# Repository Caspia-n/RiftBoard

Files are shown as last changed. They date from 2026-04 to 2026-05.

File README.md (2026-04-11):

<h1>My Project</h1>
RiftBoard is a comprehensive devboard built around the RP2040 chipset, it features a very fancy (and time consuming) ground fill, some 3v3 and some VBUS, also lots of GND. I built it mainly for testing and using sensors and actuators, either on their own or working together.
<h1>Why?</h1>
I started this project because I wanted to get into hardware design and embedded electronics. But also because I love HackClub and what they do and really wanted to be a part of this, I thank you so much for the opportunities, and I also really want a hot plate for future projects :).

<h1>Pics</h1>


RiftBoard
RiftBoardBack

<h1>BOM</h1>
<table>
    <tr>
        <td>Mrf#</td>
        <td>Mfr.</td>
        <td>Order Qty.</td>
        <td>Unit Price(USD)</td>
        <td>Ext.Price(USD)</td>
        <td>LCSC#</td>
        <td>Package</td>
        <td>Min</td>
        <td>Mult</td>
        <td>SPQ</td>
        <td>Availability</td>
        <td>Stock Status</td>
        <td>Customer Notes</td>
        <td>Description</td>
        <td>Purpose</td>
        <td>Product Link</td>
    </tr>
    <tr>
        <td>CC0402KRX7R7BB104</td>
        <td>YAGEO</td>
        <td>100</td>
        <td>0.0010</td>
        <td>0.10</td>
        <td>C60474</td>
        <td>0402</td>
        <td>100</td>
        <td>100</td>
        <td>10000</td>
        <td>11898300</td>
        <td>In Stock</td>
        <td></td>
        <td>100nF ±10% 16V Ceramic Capacitor X7R 0402</td>
        <td>Capacitors for decoupling and stabilisation of powerlines</td>
        <td>https://www.lcsc.com/product-detail/C60474.html</td>
    </tr>
    <tr>
        <td>CL05A105KP5NNNC</td>
        <td>Samsung Electro-Mechanics</td>
        <td>100</td>
        <td>0.0023</td>
        <td>0.23</td>
        <td>C14445</td>
        <td>0402</td>
        <td>100</td>
        <td>100</td>
        <td>10000</td>
        <td>1500800</td>
        <td>In Stock</td>
        <td></td>
        <td>1uF ±10% 10V Ceramic Capacitor X5R 0402</td>
        <td>One for each power line</td>
        <td>https://www.lcsc.com/product-detail/C14445.html</td>
    </tr>
    <tr>
        <td>CL10A106KP8NNNC</td>
        <td>Samsung Electro-Mechanics</td>
        <td>50</td>
        <td>0.0080</td>
        <td>0.40</td>
        <td>C19702</td>
        <td>0603</td>
        <td>50</td>
        <td>50</td>
        <td>4000</td>
        <td>3665250</td>
        <td>In Stock</td>
        <td></td>
        <td>10uF ±10% 10V Ceramic Capacitor X5R 0603</td>
        <td>Caps for the stepdown converter</td>
        <td>https://www.lcsc.com/product-detail/C19702.html</td>
    </tr>
    <tr>
        <td>CL05C330JB5NNNC</td>
        <td>Samsung Electro-Mechanics</td>
        <td>100</td>
        <td>0.0036</td>
        <td>0.36</td>
        <td>C70465</td>
        <td>0402</td>
        <td>100</td>
        <td>100</td>
        <td>10000</td>
        <td>209500</td>
        <td>In Stock</td>
        <td></td>
        <td>33pF ±5% 50V Ceramic Capacitor C0G 0402</td>
        <td>Caps for the crystal</td>
        <td>https://www.lcsc.com/product-detail/C70465.html</td>
    </tr>
    <tr>
        <td>YLED0603B</td>
        <td>YONGYUTAI</td>
        <td>100</td>
        <td>0.0060</td>
        <td>0.60</td>
        <td>C19171394</td>
        <td>0603</td>
        <td>100</td>
        <td>100</td>
        <td>4000</td>
        <td>55000</td>
        <td>In Stock</td>
        <td></td>
        <td>Blue LED Indication - Discrete 2.6V~3.2V 0603</td>
        <td>Blue programmable LED</td>
        <td>https://www.lcsc.com/product-detail/C19171394.html</td>
    </tr>
    <tr>
        <td>YLED0603R</td>
        <td>YONGYUTAI</td>
        <td>100</td>
        <td>0.0061</td>
        <td>0.61</td>
        <td>C19171390</td>
        <td>0603</td>
        <td>100</td>
        <td>100</td>
        <td>4000</td>
        <td>267100</td>
        <td>In Stock</td>
        <td></td>
        <td>Red LED Indication - Discrete 1.8V~2.4V 0603</td>
        <td>Red programmable LED</td>
        <td>https://www.lcsc.com/product-detail/C19171390.html</td>
    </tr>
    <tr>
        <td>HX TYPE-C 16PIN</td>
        <td>hanxia</td>
        <td>5</td>
        <td>0.0704</td>
        <td>0.35</td>
        <td>C5178539</td>
        <td>SMD</td>
        <td>5</td>
        <td>5</td>
        <td>1000</td>
        <td>34690</td>
        <td>In Stock</td>
        <td></td>
        <td>USB-C (USB TYPE-C) Receptacle Connector 16 Position Surface Mount, Right Angle</td>
        <td>Usb interface</td>
        <td>https://www.lcsc.com/product-detail/C5178539.html</td>
    </tr>
    <tr>
        <td>PH2.54-1X20P-H25</td>
        <td>JXTCONN</td>
        <td>10</td>
        <td>0.0920</td>
        <td>0.92</td>
        <td>C42431804</td>
        <td>Through Hole,P=2.54mm</td>
        <td>5</td>
        <td>5</td>
        <td>200</td>
        <td>9870</td>
        <td>In Stock</td>
        <td></td>
        <td>Pin Header 20 Position 2.54mm Pitch Single Row Through Hole -40℃~+105℃</td>
        <td>Main Pin headers</td>
        <td>https://www.lcsc.com/product-detail/C42431804.html</td>
    </tr>
    <tr>
        <td>HX PH254-01-03-Z-L11.5 pcb pin header</td>
        <td>hanxia</td>
        <td>20</td>
        <td>0.0192</td>
        <td>0.38</td>
        <td>C52016391</td>
        <td>Through Hole,P=2.54mm</td>
        <td>20</td>
        <td>20</td>
        <td>2000</td>
        <td>9760</td>
        <td>In Stock</td>
        <td></td>
        <td>Pin Header 1 2.5mm 6mm 3P -40℃~+105℃ 3mm 2.54mm 3A 1kV 1x3P Through Hole,P=2.54mm Headers, Male Pins RoHS</td>
        <td>3pin-connector</td>
        <td>https://www.lcsc.com/product-detail/C52016391.html</td>
    </tr>
    <tr>
        <td>RC0402FR-075K1L</td>
        <td>YAGEO</td>
        <td>100</td>
        <td>0.0009</td>
        <td>0.09</td>
        <td>C105872</td>
        <td>0402</td>
        <td>100</td>
        <td>100</td>
        <td>10000</td>
        <td>1024700</td>
        <td>In Stock</td>
        <td></td>
        <td>5.1kΩ 62.5mW 50V Thick Film Resistor ±100ppm/℃ ±1% 0402 Chip Resistor - Surface Mount RoHS</td>
        <td>Pull-down resistors for CC1/2 on usb interface</td>
        <td>https://www.lcsc.com/product-detail/C105872.html</td>
    </tr>
    <tr>
        <td>FRC0402F27R0TS</td>
        <td>FOJAN</td>
        <td>100</td>
        <td>0.0006</td>
        <td>0.06</td>
        <td>C2909343</td>
        <td>0402</td>
        <td>100</td>
        <td>100</td>
        <td>10000</td>
        <td>443300</td>
        <td>In Stock</td>
        <td></td>
        <td>27Ω ±1% 62.5mW 0402 Thick Film Resistor</td>
        <td>Resistors for the differential pair to usb interface</td>
        <td>https://www.lcsc.com/product-detail/C2909343.html</td>
    </tr>
    <tr>
        <td>RC0402FR-071KL</td>
        <td>YAGEO</td>
        <td>100</td>
        <td>0.0008</td>
        <td>0.08</td>
        <td>C106235</td>
        <td>0402</td>
        <td>100</td>
        <td>100</td>
        <td>10000</td>
        <td>5051800</td>
        <td>In Stock</td>
        <td></td>
        <td>1kΩ 62.5mW 50V Thick Film Resistor ±100ppm/℃ ±1% 0402 Chip Resistor - Surface Mount RoHS</td>
        <td>One for the crystal and one for flash mem</td>
        <td>https://www.lcsc.com/product-detail/C106235.html</td>
    </tr>
    <tr>
        <td>RC0402FR-0710KL</td>
        <td>YAGEO</td>
        <td>100</td>
        <td>0.0008</td>
        <td>0.08</td>
        <td>C60490</td>
        <td>0402</td>
        <td>100</td>
        <td>100</td>
        <td>10000</td>
        <td>1433400</td>
        <td>In Stock</td>
        <td></td>
        <td>62.5mW 10kΩ 50V Thick Film Resistor ±100ppm/℃ ±1% 0402 Chip Resistor - Surface Mount RoHS</td>
        <td>Flash mem to power resistor</td>
        <td>https://www.lcsc.com/product-detail/C60490.html</td>
    </tr>
    <tr>
        <td>FRC0402F50R0TS</td>
        <td>FOJAN</td>
        <td>100</td>
        <td>0.0006</td>
        <td>0.06</td>
        <td>C51048227</td>
        <td>0402</td>
        <td>100</td>
        <td>100</td>
        <td>10000</td>
        <td>495800</td>
        <td>In Stock</td>
        <td></td>
        <td>62.5mW 50Ω 50V Thick Film Resistor ±100ppm/℃ ±1% 0402 Chip Resistor - Surface Mount RoHS</td>
        <td>50R resistor for Red LED</td>
        <td>https://www.lcsc.com/product-detail/C51048227.html</td>
    </tr>
    <tr>
        <td>0603WAF100JT5E</td>
        <td>UNI-ROYAL</td>
        <td>20</td>
        <td>0.0017</td>
        <td>0.03</td>
        <td>C22859</td>
        <td>0603</td>
        <td>20</td>
        <td>20</td>
        <td>5000</td>
        <td>158680</td>
        <td>In Stock</td>
        <td></td>
        <td>10Ω ±1% 100mW 0603 Thick Film Resistor</td>
        <td>10R resistor for Blue LED</td>
        <td>https://www.lcsc.com/product-detail/C22859.html</td>
    </tr>
    <tr>
        <td>TS-1088-AR02016</td>
        <td>XUNPU</td>
        <td>10</td>
        <td>0.0545</td>
        <td>0.55</td>
        <td>C720477</td>
        <td>SMD,4x3mm</td>
        <td>10</td>
        <td>10</td>
        <td>4000</td>
        <td>376970</td>
        <td>In Stock</td>
        <td></td>
        <td>Tactile Switch SPST 160gf 2mm SMD (SMT) Tab 4mm x 3mm Surface Mount</td>
        <td>One switch for flash write mode, and one programmable.</td>
        <td>https://www.lcsc.com/product-detail/C720477.html</td>
    </tr>
    <tr>
        <td>RP2040</td>
        <td>Raspberry Pi</td>
        <td>5</td>
        <td>0.9482</td>
        <td>4.74</td>
        <td>C2040</td>
        <td>LQFN-56(7x7)</td>
        <td>1</td>
        <td>1</td>
        <td>3400</td>
        <td>101373</td>
        <td>In Stock</td>
        <td></td>
        <td>133MHz 30 LQFN-56(7x7) Microcontrollers RoHS</td>
        <td>The MCU on this board</td>
        <td>https://www.lcsc.com/product-detail/C2040.html</td>
    </tr>
    <tr>
        <td>MCP1700T-3302E/TT</td>
        <td>MICROCHIP</td>
        <td>5</td>
        <td>0.3762</td>
        <td>1.88</td>
        <td>C39051</td>
        <td>SOT-23</td>
        <td>5</td>
        <td>5</td>
        <td>3000</td>
        <td>9370</td>
        <td>In Stock</td>
        <td></td>
        <td>3.3V Positive Fixed SOT-23 Voltage Regulators - Linear, Low Drop Out (LDO) Regulators RoHS</td>
        <td>The stepdown converter from 5v to 3v3</td>
        <td>https://www.lcsc.com/product-detail/C39051.html</td>
    </tr>
    <tr>
        <td>W25Q16JVUXIQ</td>
        <td>Winbond</td>
        <td>10</td>
        <td>1.0529</td>
        <td>10.53</td>
        <td>C2843335</td>
        <td>USON-8-EP(2x3)</td>
        <td>10</td>
        <td>10</td>
        <td>4000</td>
        <td>34380</td>
        <td>In Stock</td>
        <td></td>
        <td>2.7V~3.6V 16Mbit 133MHz SPI USON-8-EP(2x3) Memory (ICs) RoHS</td>
        <td>The flash memory module</td>
        <td>https://www.lcsc.com/product-detail/C2843335.html</td>
    </tr>
    <tr>
        <td>X322512MSB4SI</td>
        <td>YXC Crystal Oscillators</td>
        <td>10</td>
        <td>0.0734</td>
        <td>0.73</td>
        <td>C9002</td>
        <td>SMD3225-4P</td>
        <td>10</td>
        <td>10</td>
        <td>3000</td>
        <td>436800</td>
        <td>In Stock</td>
        <td></td>
        <td>Crystal 12MHz ±10ppm 20pF SMD3225-4P</td>
        <td>the Crystal oscilator</td>
        <td>https://www.lcsc.com/product-detail/C9002.html</td>
    </tr>
</table>

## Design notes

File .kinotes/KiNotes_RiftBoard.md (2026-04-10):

# **RiftBoard - Design Notes**

## ********************************************PCB layout time [2026-04-07 9:40]********************************************
I made a Differential pair for usb data routing [2026-04-07 9:45] 
Added Decoupling caps for step-down and power lines [2026-04-07 10:00] 
Logoff [2026-04-07 10:19] 
Logon [2026-04-07 10:45] 
All components placed, wil commence routing algorithm to see how good it works. [2026-04-07 11:09] 
Algorithm took too long, started manual routing [2026-04-07 11:30] 
Log off [2026-04-07 12:13] 
Log on [2026-04-07 17:15] 
Had problems with some of the GPIOs as the chip has them in top to bottom while the pin header has it the other way around, I am going to keep trying to make it work, if not then I will flip the row around. [2026-04-07 17:31] 
I reassigned all the GPIOs, both the right header row and for the button and leds, this should make it easier to route. [2026-04-07 18:03] 

Started tracing with the reassigned GPIOs, the first part that had to go around the decoupling caps was quite difficult. [2026-04-08 10:30]
Finished routing, left all the GND pins, and connected all 3v3's together and vbus pins together too. [2026-04-08 10:48] 

I unrounded all the tracks, as I noticed it actually made the differential pair wrong, and I was unable to fix it, so I unrounded everything and retuned the traces. I also discovered that I forgot to combine D- + D- and D+ + D+.[2026-04-08 10:57] 

Logoff [2026-04-08 10:58] 
Logon [2026-04-08 12:07] 
Ground fill done, it took a lot of rerouting and vias to connect everything, but it worked out in the end. There was a wierd misalignment between the MCU and the tracks, so I had to lower the spacing, and some plces now have a 0.192 or 0.194 mm spacing instead of 0.2mm, I assed that this should work out fine as it will be the lower power gpio pins. [2026-04-08 12:28] 
Ran DRC and got quite the package, of course the minimum spcing that I just mentioned, and then isolated GND islands, but they weren't really isolated.
Labled everything, so silkscreen shows every component ID [2026-04-08 12:43] 
Connected and reinforced most ground fill parts [2026-04-08 13:00] 
DRC is as clean as it will get, I am happy, now time for the art and stuff [2026-04-08 13:03] 
Logoff[2026-04-08 13:38] 
Logon[2026-04-08 14:52] 
I spent quite some time getting a nice design, now I got it and will
Logoff [2026-04-08 15:18] 
Fishing up design placement and little ornaments [2026-04-10 08:50] 
I am happy with the design and how the baord looks, I will now get the fabrication outputs done using a plugin that automatically makes it JLCPCB compatible. [2026-04-10 09:01] 
I had to replace the 14pin connector, because it wasnt availible on JLC, No I have to slightly change some routing. [2026-04-10 09:25] 
I did some digging and found out that the crystal oscilator's orientation does not matter as long as the ground pads are on ground, so pin 1 and 3 are interchangeable, I will not do PCBA, because when I looked it was 80AUD because of the parts from extended library. [2026-04-10 10:13] 
Logoff [2026-04-10 10:15]

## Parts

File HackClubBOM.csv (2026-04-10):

Mrf# | Mfr. | Order Qty. | Unit Price(USD) | Ext.Price(USD) | LCSC# | Package | Min | Mult | SPQ | Availability | Stock Status | Customer Notes | Description | Purpose | Product Link
CC0402KRX7R7BB104 | YAGEO | 100 | 0.0010 | 0.10 | C60474 | 0402 | 100 | 100 | 10000 | 11898300 | In Stock |  | 100nF ±10% 16V Ceramic Capacitor X7R 0402 | Capacitors for decoupling and stabilisation of powerlines | https://www.lcsc.com/product-detail/C60474.html
CL05A105KP5NNNC | Samsung Electro-Mechanics | 100 | 0.0023 | 0.23 | C14445 | 0402 | 100 | 100 | 10000 | 1500800 | In Stock |  | 1uF ±10% 10V Ceramic Capacitor X5R 0402 | One for each power line | https://www.lcsc.com/product-detail/C14445.html
CL10A106KP8NNNC | Samsung Electro-Mechanics | 50 | 0.0080 | 0.40 | C19702 | 0603 | 50 | 50 | 4000 | 3665250 | In Stock |  | 10uF ±10% 10V Ceramic Capacitor X5R 0603 | Caps for the stepdown converter | https://www.lcsc.com/product-detail/C19702.html
CL05C330JB5NNNC | Samsung Electro-Mechanics | 100 | 0.0036 | 0.36 | C70465 | 0402 | 100 | 100 | 10000 | 209500 | In Stock |  | 33pF ±5% 50V Ceramic Capacitor C0G 0402 | Caps for the crystal | https://www.lcsc.com/product-detail/C70465.html
YLED0603B | YONGYUTAI | 100 | 0.0060 | 0.60 | C19171394 | 0603 | 100 | 100 | 4000 | 55000 | In Stock |  | Blue LED Indication - Discrete 2.6V~3.2V 0603 | Blue programmable LED | https://www.lcsc.com/product-detail/C19171394.html
YLED0603R | YONGYUTAI | 100 | 0.0061 | 0.61 | C19171390 | 0603 | 100 | 100 | 4000 | 267100 | In Stock |  | Red LED Indication - Discrete 1.8V~2.4V 0603 | Red programmable LED | https://www.lcsc.com/product-detail/C19171390.html
HX TYPE-C 16PIN | hanxia | 5 | 0.0704 | 0.35 | C5178539 | SMD | 5 | 5 | 1000 | 34690 | In Stock |  | USB-C (USB TYPE-C) Receptacle Connector 16 Position Surface Mount, Right Angle | Usb interface | https://www.lcsc.com/product-detail/C5178539.html
PH2.54-1X20P-H25 | JXTCONN | 10 | 0.0920 | 0.92 | C42431804 | Through Hole,P=2.54mm | 5 | 5 | 200 | 9870 | In Stock |  | Pin Header 20 Position 2.54mm Pitch Single Row Through Hole -40℃~+105℃ | Main Pin headers | https://www.lcsc.com/product-detail/C42431804.html
HX PH254-01-03-Z-L11.5 pcb pin header | hanxia | 20 | 0.0192 | 0.38 | C52016391 | Through Hole,P=2.54mm | 20 | 20 | 2000 | 9760 | In Stock |  | Pin Header 1 2.5mm 6mm 3P -40℃~+105℃ 3mm 2.54mm 3A 1kV 1x3P Through Hole,P=2.54mm Headers, Male Pins RoHS | 3pin-connector | https://www.lcsc.com/product-detail/C52016391.html
RC0402FR-075K1L | YAGEO | 100 | 0.0009 | 0.09 | C105872 | 0402 | 100 | 100 | 10000 | 1024700 | In Stock |  | 5.1kΩ 62.5mW 50V Thick Film Resistor ±100ppm/℃ ±1% 0402 Chip Resistor - Surface Mount RoHS | Pull-down resistors for CC1/2 on usb interface | https://www.lcsc.com/product-detail/C105872.html
FRC0402F27R0TS | FOJAN | 100 | 0.0006 | 0.06 | C2909343 | 0402 | 100 | 100 | 10000 | 443300 | In Stock |  | 27Ω ±1% 62.5mW 0402 Thick Film Resistor | Resistors for the differential pair to usb interface | https://www.lcsc.com/product-detail/C2909343.html
RC0402FR-071KL | YAGEO | 100 | 0.0008 | 0.08 | C106235 | 0402 | 100 | 100 | 10000 | 5051800 | In Stock |  | 1kΩ 62.5mW 50V Thick Film Resistor ±100ppm/℃ ±1% 0402 Chip Resistor - Surface Mount RoHS | One for the crystal and one for flash mem | https://www.lcsc.com/product-detail/C106235.html
RC0402FR-0710KL | YAGEO | 100 | 0.0008 | 0.08 | C60490 | 0402 | 100 | 100 | 10000 | 1433400 | In Stock |  | 62.5mW 10kΩ 50V Thick Film Resistor ±100ppm/℃ ±1% 0402 Chip Resistor - Surface Mount RoHS | Flash mem to power resistor | https://www.lcsc.com/product-detail/C60490.html
FRC0402F50R0TS | FOJAN | 100 | 0.0006 | 0.06 | C51048227 | 0402 | 100 | 100 | 10000 | 495800 | In Stock |  | 62.5mW 50Ω 50V Thick Film Resistor ±100ppm/℃ ±1% 0402 Chip Resistor - Surface Mount RoHS | 50R resistor for Red LED | https://www.lcsc.com/product-detail/C51048227.html
0603WAF100JT5E | UNI-ROYAL | 20 | 0.0017 | 0.03 | C22859 | 0603 | 20 | 20 | 5000 | 158680 | In Stock |  | 10Ω ±1% 100mW 0603 Thick Film Resistor | 10R resistor for Blue LED | https://www.lcsc.com/product-detail/C22859.html
TS-1088-AR02016 | XUNPU | 10 | 0.0545 | 0.55 | C720477 | SMD,4x3mm | 10 | 10 | 4000 | 376970 | In Stock |  | Tactile Switch SPST 160gf 2mm SMD (SMT) Tab 4mm x 3mm Surface Mount | One switch for flash write mode, and one programmable. | https://www.lcsc.com/product-detail/C720477.html
RP2040 | Raspberry Pi | 5 | 0.9482 | 4.74 | C2040 | LQFN-56(7x7) | 1 | 1 | 3400 | 101373 | In Stock |  | 133MHz 30 LQFN-56(7x7) Microcontrollers RoHS | The MCU on this board | https://www.lcsc.com/product-detail/C2040.html
MCP1700T-3302E/TT | MICROCHIP | 5 | 0.3762 | 1.88 | C39051 | SOT-23 | 5 | 5 | 3000 | 9370 | In Stock |  | 3.3V Positive Fixed SOT-23 Voltage Regulators - Linear, Low Drop Out (LDO) Regulators RoHS | The stepdown converter from 5v to 3v3 | https://www.lcsc.com/product-detail/C39051.html
W25Q16JVUXIQ | Winbond | 10 | 1.0529 | 10.53 | C2843335 | USON-8-EP(2x3) | 10 | 10 | 4000 | 34380 | In Stock |  | 2.7V~3.6V 16Mbit 133MHz SPI USON-8-EP(2x3) Memory (ICs) RoHS | The flash memory module | https://www.lcsc.com/product-detail/C2843335.html
X322512MSB4SI | YXC Crystal Oscillators | 10 | 0.0734 | 0.73 | C9002 | SMD3225-4P | 10 | 10 | 3000 | 436800 | In Stock |  | Crystal 12MHz ±10ppm 20pF SMD3225-4P | the Crystal oscilator | https://www.lcsc.com/product-detail/C9002.html

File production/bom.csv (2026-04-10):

Designator | Footprint | Quantity | Value | LCSC Part #
C1, C10, C11, C2, C26, C3, C4, C5, C6, C7, C8 | 0402 | 11 | 0.1uF
C12, C9 | 0402 | 2 | 1uF
C22, C23 | 0603 | 2 | 10uF
C24, C25 | 0402 | 2 | 33pF
D1 | 0603 | 1 | BLUE
D2 | 0603 | 1 | RED
J1 | USB_C_Receptacle_HRO_TYPE-C-31-M-12 | 1 | USB_C_Receptacle_USB2.0_16P
J2, J3 | PinHeader_1x20_P2.54mm_Vertical | 2 | Conn_01x20
J4 | PinHeader_1x03_P2.54mm_Vertical | 1 | Conn_01x03
R1, R2 | 0402 | 2 | 5.1K
R3, R4 | 0402 | 2 | 27
R5, R7 | 0402 | 2 | 1K
R6 | 0402 | 1 | 10k
R8 | 0402 | 1 | 50
R9 | 0402 | 1 | 10
SW1, SW2 | SW_Push_SPST_NO_Alps_SKRK | 2 | SW_Push
U1 | QFN-56-1EP_7x7mm_P0.4mm_EP3.2x3.2mm | 1 | RP2040
U2 | SOT-23 | 1 | MCP1700x-330xxTT
U3 | Winbond_USON-8-1EP_3x2mm_P0.5mm_EP0.2x1.6mm | 1 | W25Q16JVUXIQ TR
Y1 | Crystal_SMD_3225-4Pin_3.2x2.5mm | 1 | 12MHz

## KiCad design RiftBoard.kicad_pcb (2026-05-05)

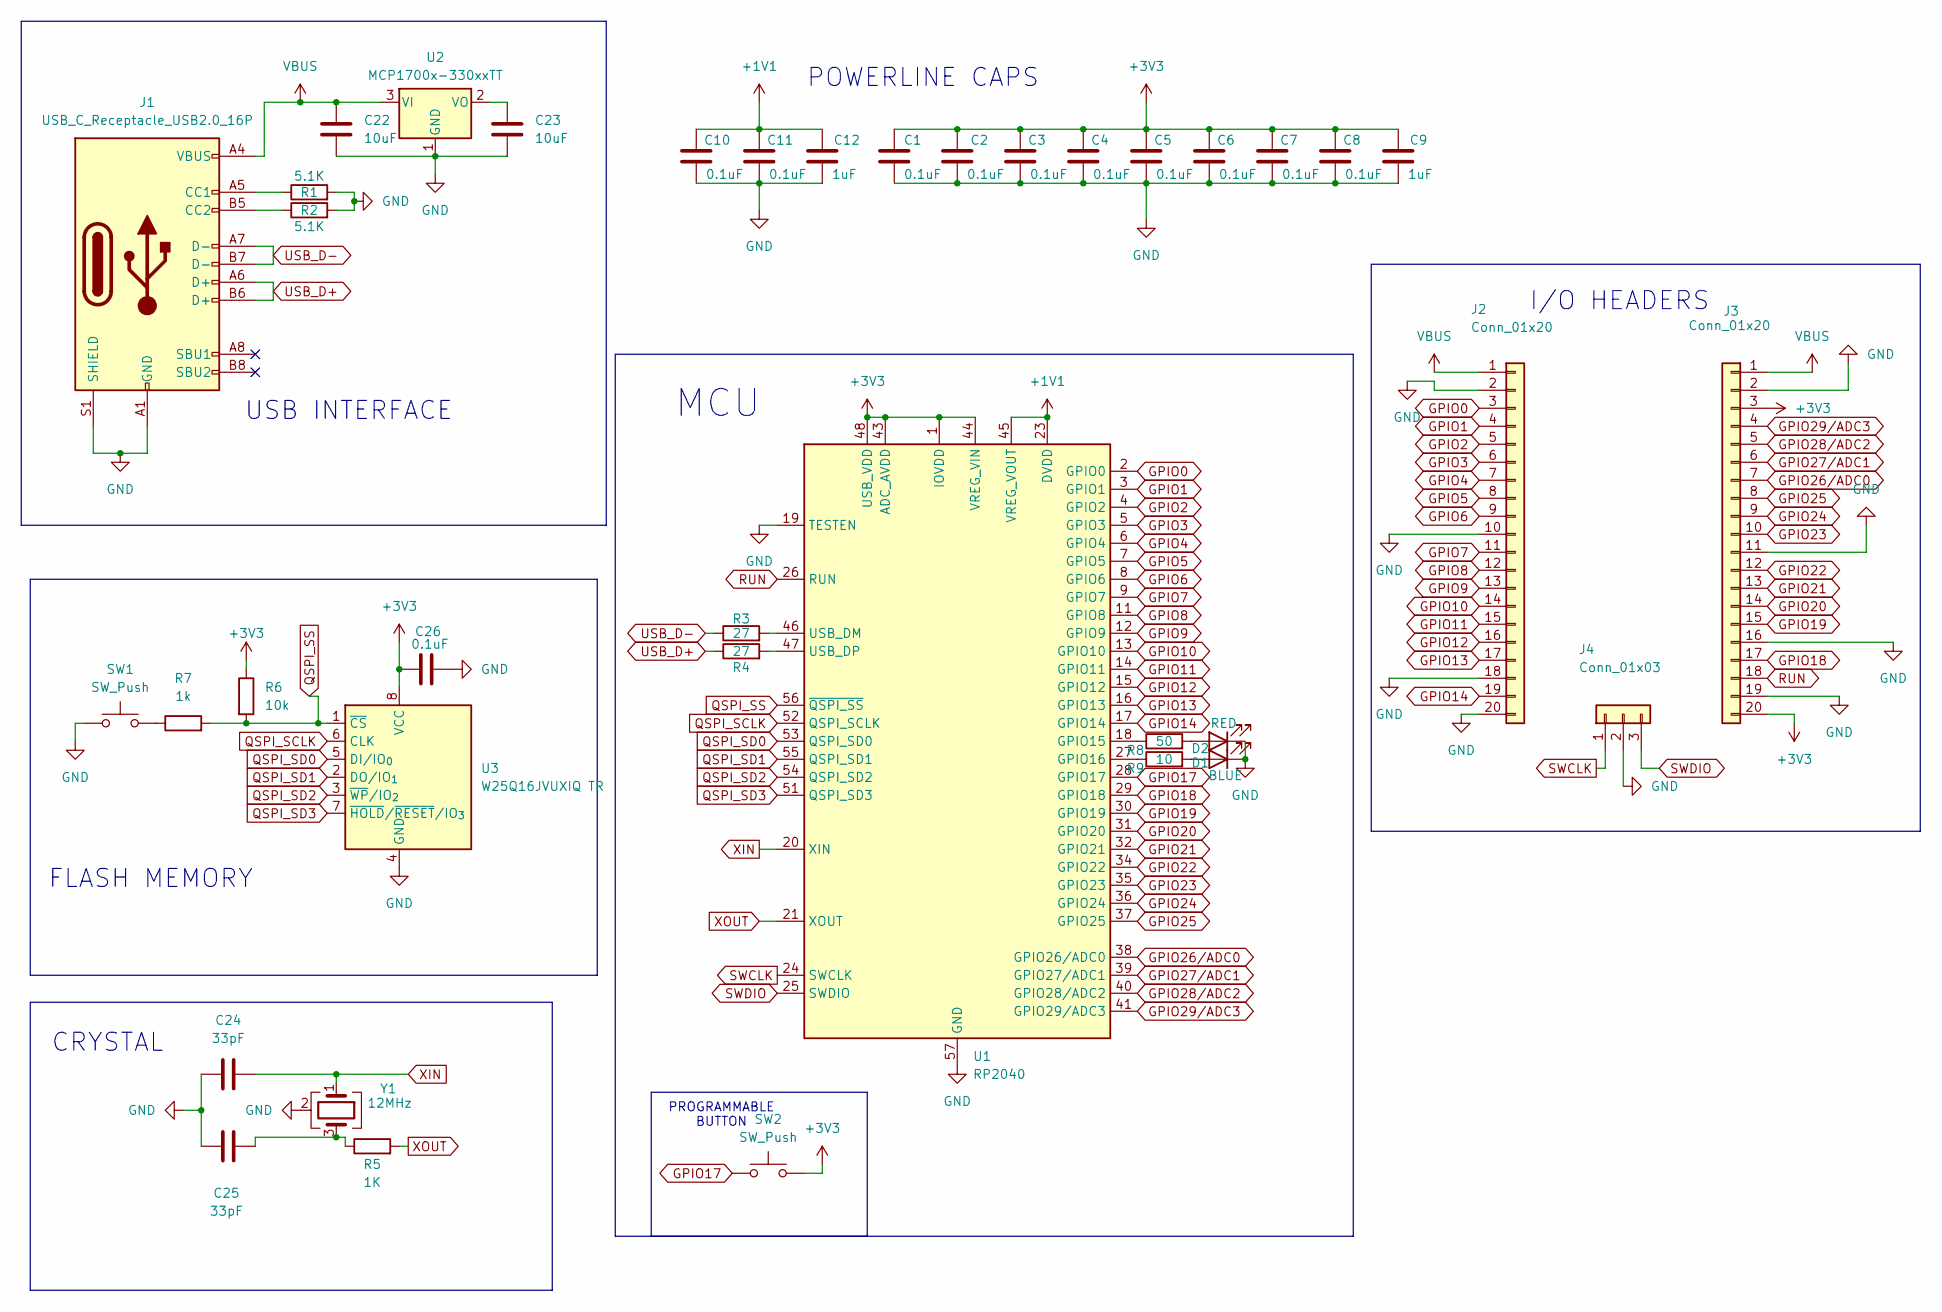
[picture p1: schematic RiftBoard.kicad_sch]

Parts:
C1, C2, C3, C4, C5, C6, C7, C8, C10, C11, C26: 0.1uF; C_0402_1005Metric
C9, C12: 1uF; C_0402_1005Metric
C22, C23: 10uF; C_0603_1608Metric
C24, C25: 33pF; C_0402_1005Metric
D1: BLUE; LED_0603_1608Metric
D2: RED; LED_0603_1608Metric
J1: USB_C_Receptacle_USB2.0_16P; USB_C_Receptacle_HRO_TYPE-C-31-M-12
J2, J3: Conn_01x20; PinHeader_1x20_P2.54mm_Vertical
J4: Conn_01x03; PinHeader_1x03_P2.54mm_Vertical
R1, R2: 5.1K; R_0402_1005Metric
R3, R4: 27; R_0402_1005Metric
R5: 1K; R_0402_1005Metric
R6: 10k; R_0402_1005Metric
R7: 1k; R_0402_1005Metric
R8: 50; R_0402_1005Metric
R9: 10; R_0402_1005Metric
SW1, SW2: SW_Push; SW_Push_SPST_NO_Alps_SKRK
U1: RP2040; QFN-56-1EP_7x7mm_P0.4mm_EP3.2x3.2mm
U2: MCP1700x-330xxTT; SOT-23
U3: W25Q16JVUXIQ TR; Winbond_USON-8-1EP_3x2mm_P0.5mm_EP0.2x1.6mm
Y1: 12MHz; Crystal_SMD_3225-4Pin_3.2x2.5mm

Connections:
+1V1: C10.1, C11.1, C12.1, U1.23 (DVDD), U1.45 (VREG_VOUT), U1.50 (DVDD)
+3V3: C1.1, C2.1, C3.1, C4.1, C5.1, C6.1, C7.1, C8.1, C9.1, C26.1, J3.3, J3.20, R6.1, SW2.2, U1.1 (IOVDD), U1.10 (IOVDD), U1.22 (IOVDD), U1.33 (IOVDD), U1.42 (IOVDD), U1.43 (ADC_AVDD), U1.44 (VREG_VIN), U1.48 (USB_VDD), U1.49 (IOVDD), U3.8 (VCC)
GND: C1.2, C2.2, C3.2, C4.2, C5.2, C6.2, C7.2, C8.2, C9.2, C10.2, C11.2, C12.2, C22.2, C23.2, C24.1, C25.1, C26.2, D1.1 (K), D2.1 (K), J1.A1 (GND), J1.A12 (GND), J1.B1 (GND), J1.B12 (GND), J1.S1 (SHIELD), J1.SH (SHIELD), J2.2, J2.10, J2.18, J2.20, J3.2, J3.11, J3.16, J3.19, J4.2, R1.2, R2.2, SW1.1, U1.19 (TESTEN), U1.57 (GND), U2.1 (GND), U3.4 (GND), Y1.2 (G), Y1.4 (G)
GPIO0: J2.3, U1.2 (GPIO0)
GPIO1: J2.4, U1.3 (GPIO1)
GPIO2: J2.5, U1.4 (GPIO2)
GPIO3: J2.6, U1.5 (GPIO3)
GPIO4: J2.7, U1.6 (GPIO4)
GPIO5: J2.8, U1.7 (GPIO5)
GPIO6: J2.9, U1.8 (GPIO6)
GPIO7: J2.11, U1.9 (GPIO7)
GPIO8: J2.12, U1.11 (GPIO8)
GPIO9: J2.13, U1.12 (GPIO9)
GPIO10: J2.14, U1.13 (GPIO10)
GPIO11: J2.15, U1.14 (GPIO11)
GPIO12: J2.16, U1.15 (GPIO12)
GPIO13: J2.17, U1.16 (GPIO13)
GPIO14: J2.19, U1.17 (GPIO14)
GPIO17: SW2.1, U1.28 (GPIO17)
GPIO18: J3.17, U1.29 (GPIO18)
GPIO19: J3.15, U1.30 (GPIO19)
GPIO20: J3.14, U1.31 (GPIO20)
GPIO21: J3.13, U1.32 (GPIO21)
GPIO22: J3.12, U1.34 (GPIO22)
GPIO23: J3.10, U1.35 (GPIO23)
GPIO24: J3.9, U1.36 (GPIO24)
GPIO25: J3.8, U1.37 (GPIO25)
GPIO26/ADC0: J3.7, U1.38 (GPIO26/ADC0)
GPIO27/ADC1: J3.6, U1.39 (GPIO27/ADC1)
GPIO28/ADC2: J3.5, U1.40 (GPIO28/ADC2)
GPIO29/ADC3: J3.4, U1.41 (GPIO29/ADC3)
unnamed: C25.2, R5.1, Y1.3
unnamed: D1.2 (A), R9.2
unnamed: D2.2 (A), R8.2
unnamed: J1.A5 (CC1), R1.1
unnamed: J1.B5 (CC2), R2.1
unnamed: R7.1, SW1.2
unnamed: R8.1, U1.18 (GPIO15)
unnamed: R9.1, U1.27 (GPIO16)
unnamed: R3.2, U1.46 (USB_DM)
unnamed: R4.2, U1.47 (USB_DP)
unnamed: C23.1, U2.2 (VO)
QSPI_SCLK: U1.52 (QSPI_SCLK), U3.6 (CLK)
QSPI_SD0: U1.53 (QSPI_SD0), U3.5 (DI/IO_{0})
QSPI_SD1: U1.55 (QSPI_SD1), U3.2 (DO/IO_{1})
QSPI_SD2: U1.54 (QSPI_SD2), U3.3 (~WP/IO_{2})
QSPI_SD3: U1.51 (QSPI_SD3), U3.7 (~HOLD/~RESET/IO_{3})
QSPI_SS: R6.2, R7.2, U1.56 (~QSPI_SS), U3.1 (~CS)
RUN: J3.18, U1.26 (RUN)
SWCLK: J4.1, U1.24 (SWCLK)
SWDIO: J4.3, U1.25 (SWDIO)
USB_D+: J1.A6 (D+), J1.B6 (D+), R4.1
USB_D-: J1.A7 (D-), J1.B7 (D-), R3.1
VBUS: C22.1, J1.A4 (VBUS), J1.A9 (VBUS), J1.B4 (VBUS), J1.B9 (VBUS), J2.1, J3.1, U2.3 (VI)
XIN: C24.2, U1.20 (XIN), Y1.1
XOUT: R5.2, U1.21 (XOUT)

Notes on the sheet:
POWERLINE CAPS
CRYSTAL
USB INTERFACE
I/O HEADERS
FLASH MEMORY
MCU
PROGRAMMABLE BUTTON

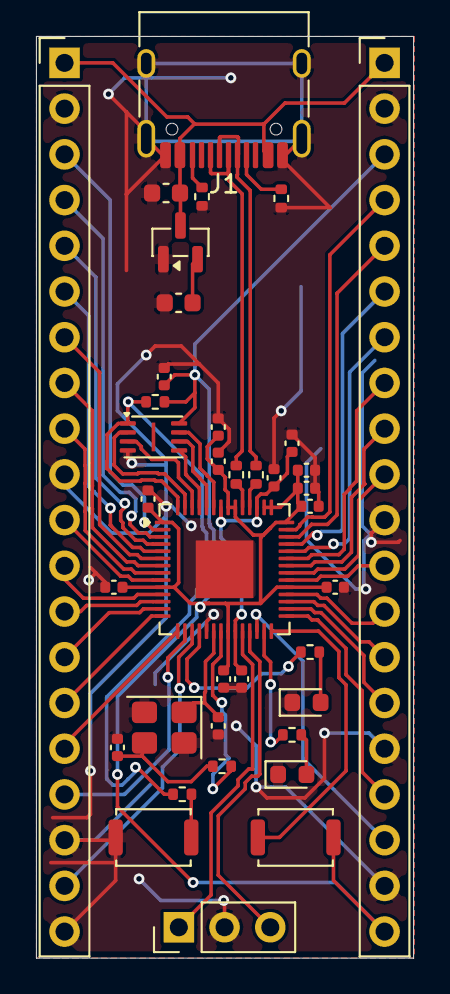
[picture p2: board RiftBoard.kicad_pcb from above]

Board: 2 copper layers, 21.0 x 51.2 mm, 38 parts (0 on the bottom side), 56 nets.

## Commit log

2026-04-06 Project Init
    [RiftBoard.kicad_pcb, RiftBoard.kicad_sch]
2026-04-07 10:19 logoff
    Decoupling caps, and differential data line done
    [RiftBoard.kicad_pcb, freerouting.dsn, temp-freerouting.dsn]
2026-04-07 Failed to trace without swapping gpio around, Im going to flip pin header for better compatibility with rp2040.
    [RiftBoard.kicad_pcb, freerouting.dsn, temp-freerouting.dsn]
2026-04-08 Finished PCB stuffs, now just design and I can move on to the production and assembly.
    [RiftBoard.kicad_pcb, RiftBoard.kicad_sch]
2026-04-10 Document schematic and PCB design progress in README
2026-04-10 Revise README with project overview and BOM
    Updated the README to include project details, BOM, and images.
2026-04-10 Replace BOM and remove gerber/placement files
    Remove legacy BOM and Gerber/placement exports and add a new LCSC-ready BOM. Deleted: HackClubbom.csv, gerber_to_order/RiftBoard-top-pos.csv, gerber_to_order/RiftBoard-bottom-pos.csv, and gerber_to_order/RiftBoard_20.95x51.2mm_for_JLCPCB.zip. Added: hcBOM.csv containing updated manufacturer numbers, order quantities, unit prices, LCSC part IDs and product links for all board components to streamline parts ordering.
    [HackClubbom.csv, hcBOM.csv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]
2026-05-05 Hopefully final fix
    [HackClubBOM.csv, RiftBoard.kicad_pcb, RiftBoard.kicad_sch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]
